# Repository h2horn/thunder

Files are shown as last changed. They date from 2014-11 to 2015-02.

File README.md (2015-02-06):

Lightning Thunder
=================

Controlling [LPD8806](https://www.adafruit.com/products/306) based LED Strips over Network.

* control up to 4 LPD8806 based LED Strips
* simple UDP Protocol

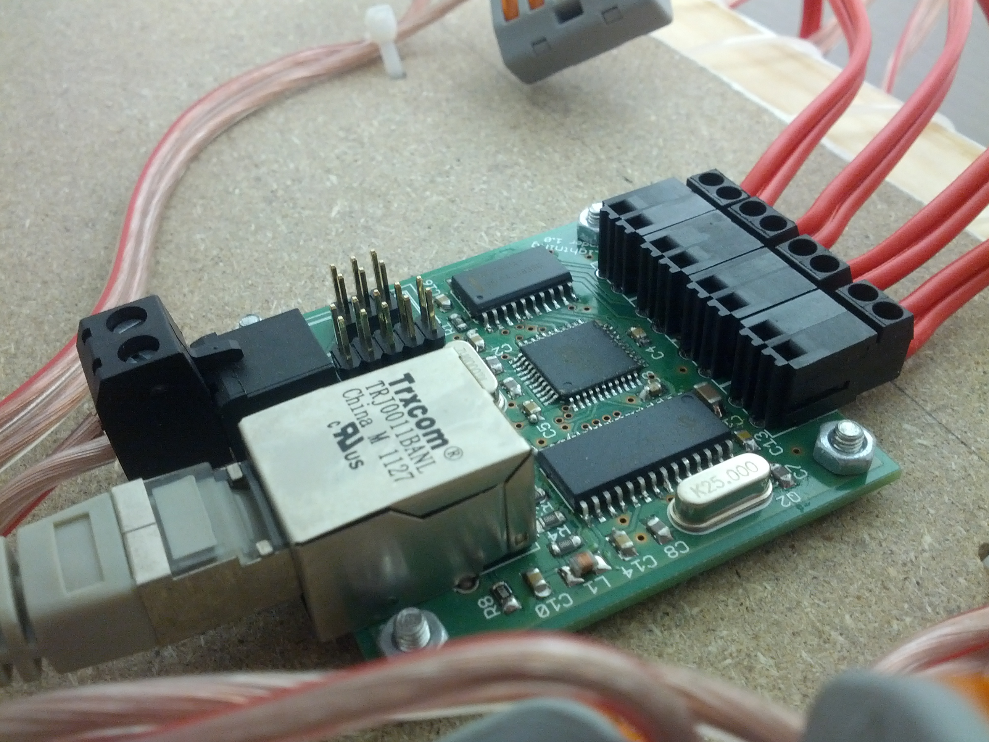
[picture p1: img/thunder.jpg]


Components
----------

Based on:

* [ATxmega16A4](http://www.atmel.com/Images/Atmel-8331-8-and-16-bit-AVR-Microcontroller-XMEGA-AU_Manual.pdf) - Low power, high performance 8/16-bit AVR microcontroller
* [ENC28J60](http://ww1.microchip.com/downloads/en/DeviceDoc/39662e.pdf) - Microchip 10Mbit Ethernet controller with SPI interface

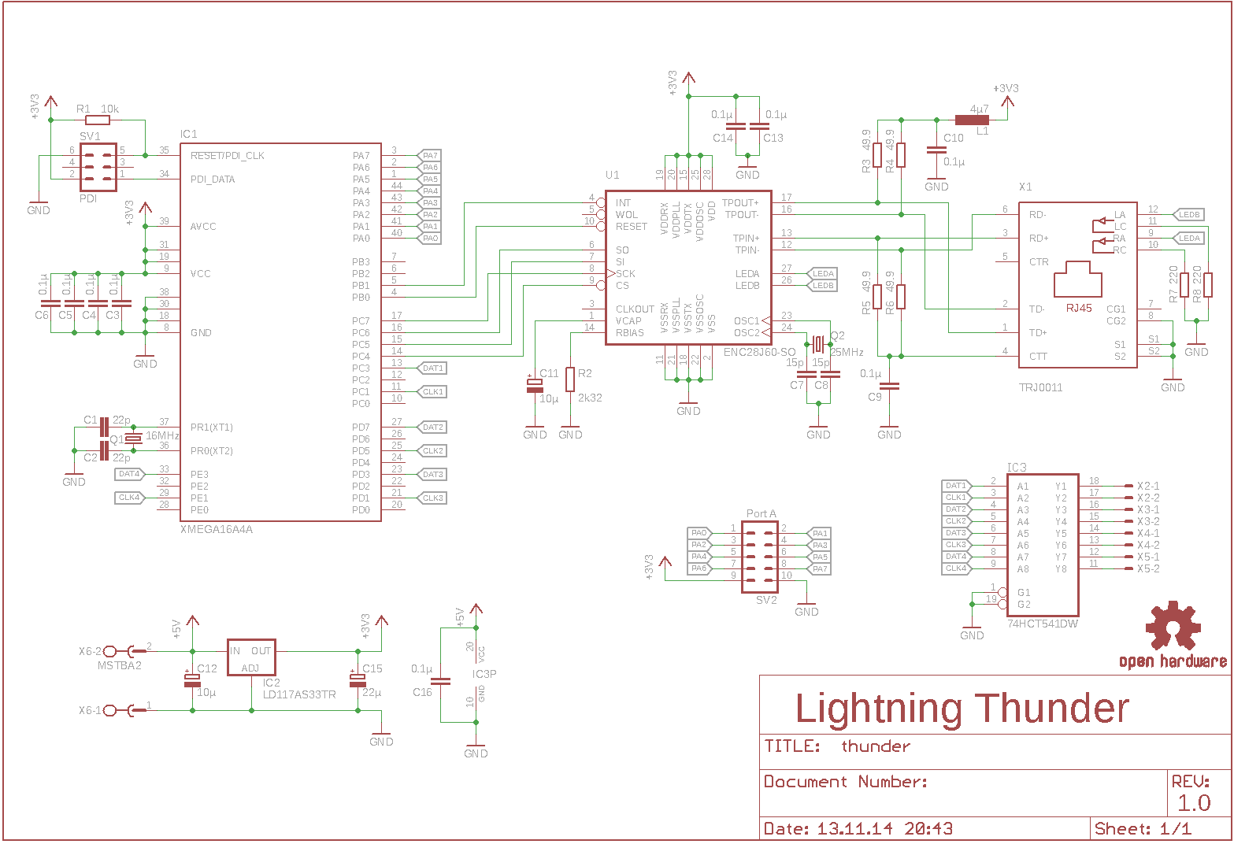
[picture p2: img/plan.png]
plan


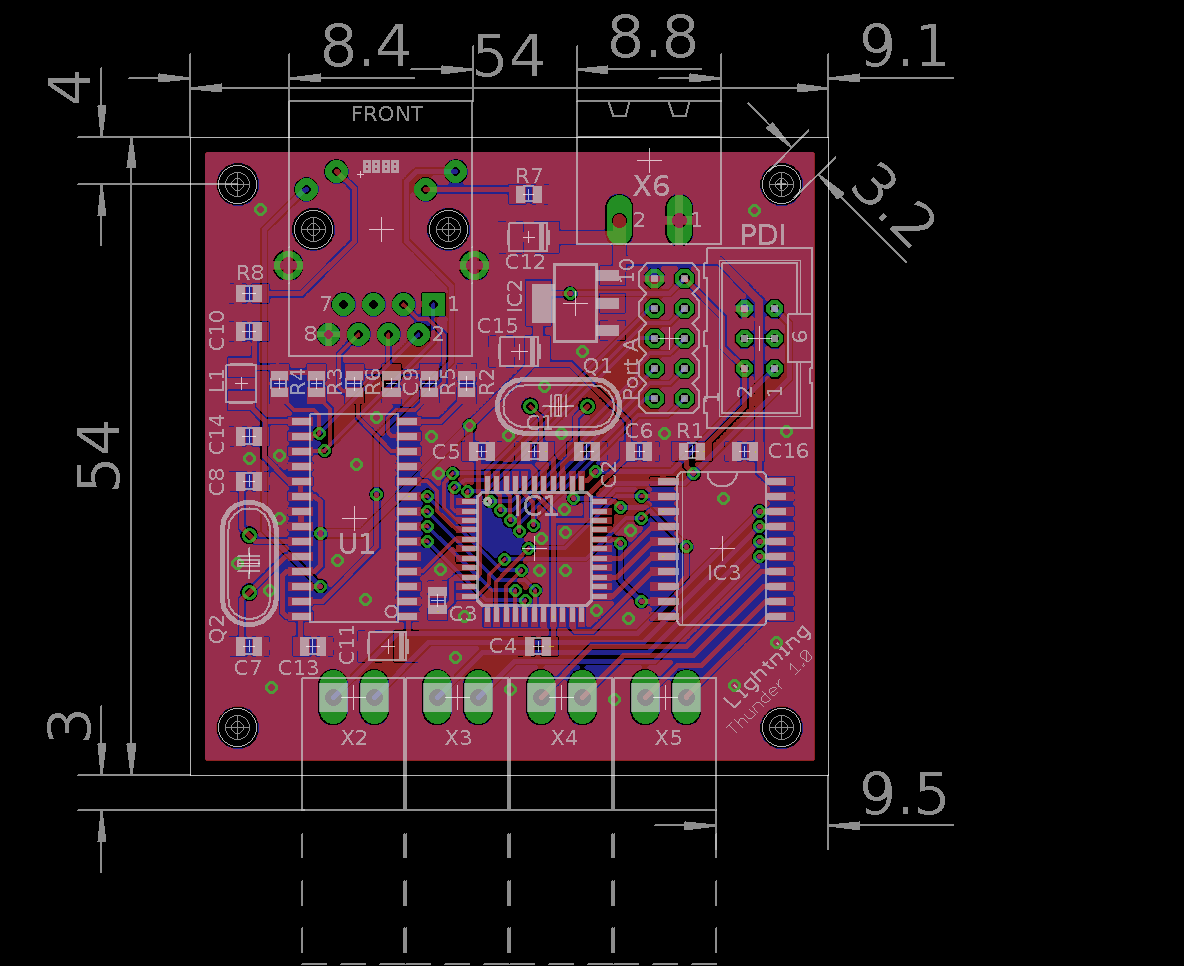
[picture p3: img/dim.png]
dim


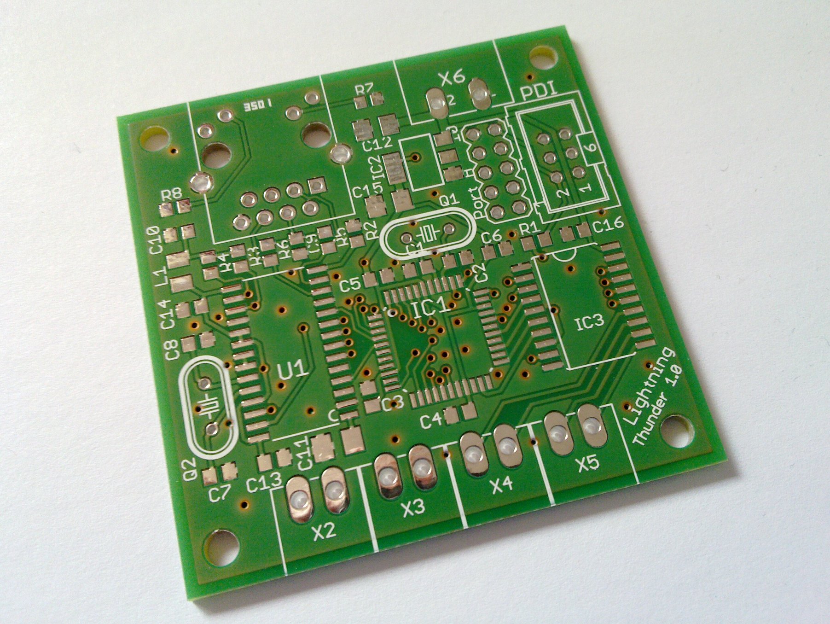
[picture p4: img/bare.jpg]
bare


Protocol
--------

`Thunder` recieves UDP data containing the raw LPD8806 data for each Strip
on seperate UDP Ports (50000-50003). It forwards the data directly over SPI, without any checking or modification.

The Host has full control and has to calculate the correct order and
color ordering (RBG -> RGB), etc...

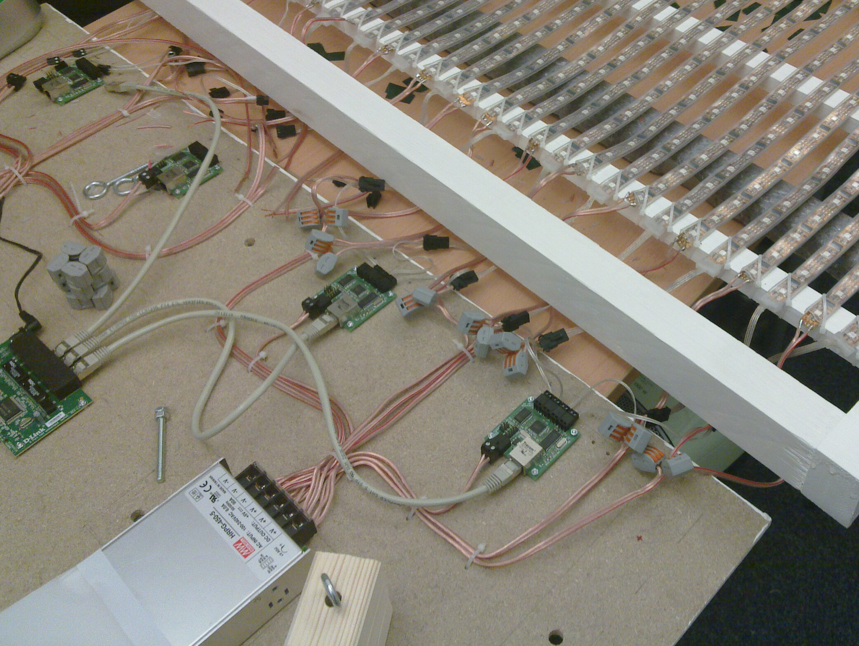
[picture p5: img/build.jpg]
build


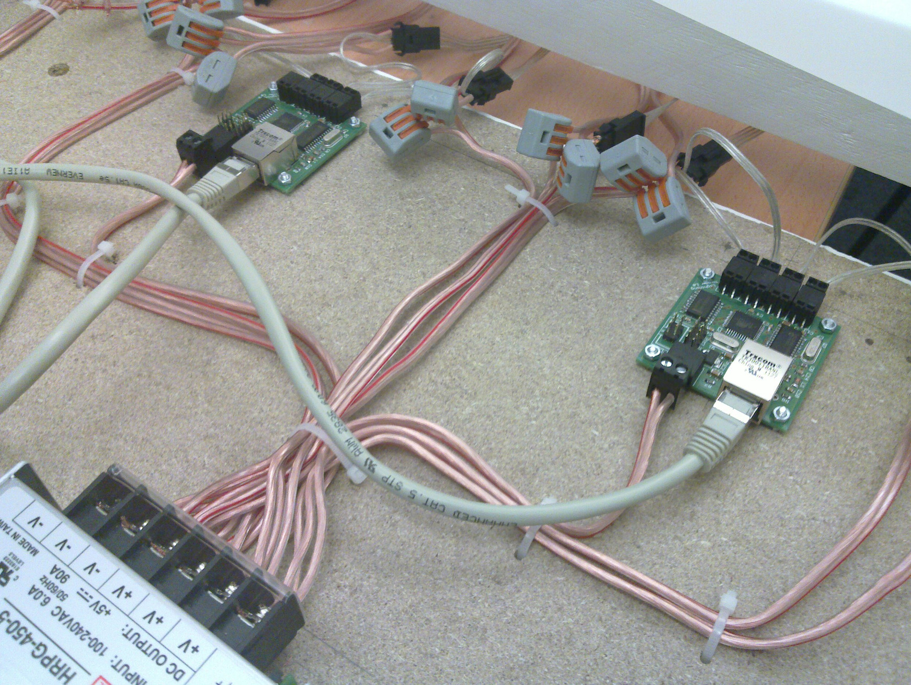
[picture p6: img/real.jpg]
real


Result
------

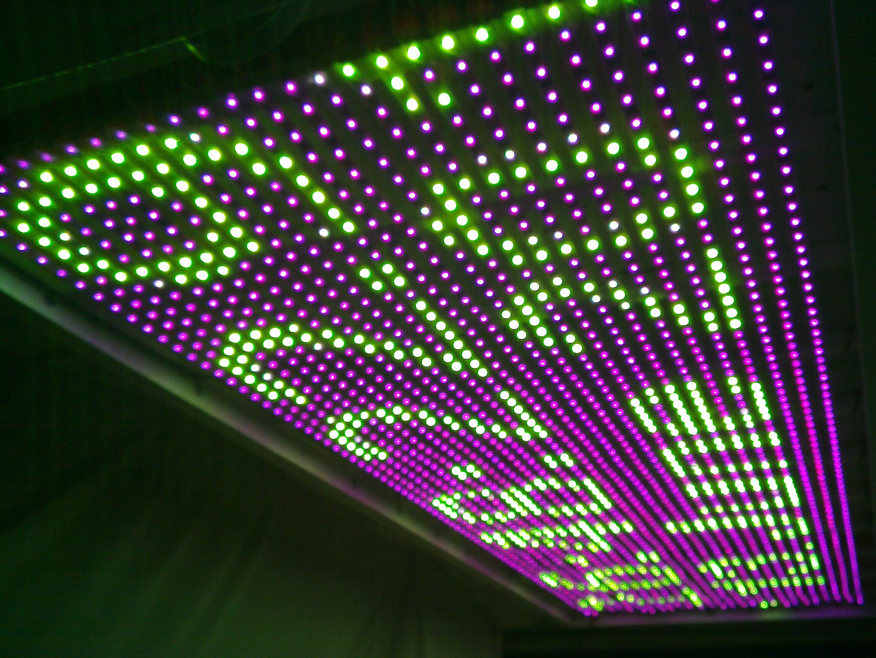
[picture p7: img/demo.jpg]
demo


LICENSE
-------

Released under the [MIT](http://opensource.org/licenses/MIT) License.
Based on the [Open Source Hardware Definition v1.0](http://www.oshwa.org/definition/).

See the respective source code files for varying Licenses.

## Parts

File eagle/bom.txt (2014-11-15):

Qty Value       Device            Package     Parts                                  Description
2   22p         C-EUC0805         C0805       C1, C2                                 CAPACITOR, European symbol
9   0.1µ        C-EUC0805         C0805       C3, C4, C5, C6, C9, C10, C13, C14, C16 CAPACITOR, European symbol
2   15p         C-EUC0805         C0805       C7, C8                                 CAPACITOR, European symbol
2   10µ         CPOL-EUB/3528-21R B/3528-21R  C11, C12                               POLARIZED CAPACITOR, European symbol
1   22µ         CPOL-EUB/3528-21R B/3528-21R  C15                                    POLARIZED CAPACITOR, European symbol
1   10k         R-EU_R0805        R0805       R1                                     RESISTOR, European symbol
2   220         R-EU_R0805        R0805       R7, R8                                 RESISTOR, European symbol
1   2k32        R-EU_R0805        R0805       R2                                     RESISTOR, European symbol
4   49.9        R-EU_R0805        R0805       R3, R4, R5, R6                         RESISTOR, European symbol
1   16MHz       CRYSTALHC49U-V    HC49U-V     Q1                                     CRYSTAL
1   25MHz       CRYSTALHC49U-V    HC49U-V     Q2                                     CRYSTAL
1   4µ7         L-EUL3225M        L3225M      L1                                     INDUCTOR, European symbol
1   XMEGA16A4A  XMEGA16A4A        TQFP44      IC1                                    MICROCONTROLLER
1   ENC28J60-SO ENC28J60-SO       SO28W       U1                                     Microchip 10Mbit Ethernet controller with SPI interface
1   LD117AS33TR LD117AS33TR       SOT223      IC2                                    Low drop fixed and adjustable positive voltage regulators 1 A
1   74HCT541DW  74HCT541DW        SO20W       IC3                                    Octal BUFFER and LINE DRIVER, 3-state
1   TRJ0011     TRJ0011           TRJ0011     X1                                     10/100Base-TX RJ45 Connector With Integrated Magnetics(Tab-Down)
4   AKL18X-02W  AKL18X-02W        AKL182-02   X2, X3, X4, X5                         Riacon AKL18X Steckverbinder
1   MSTBA2      MSTBA2            MSTBA2      X6                                     PHOENIX
1   PDI         ML6               ML6         SV1                                    HARTING
1   Port A      MA05-2            MA05-2      SV2                                    PIN HEADER

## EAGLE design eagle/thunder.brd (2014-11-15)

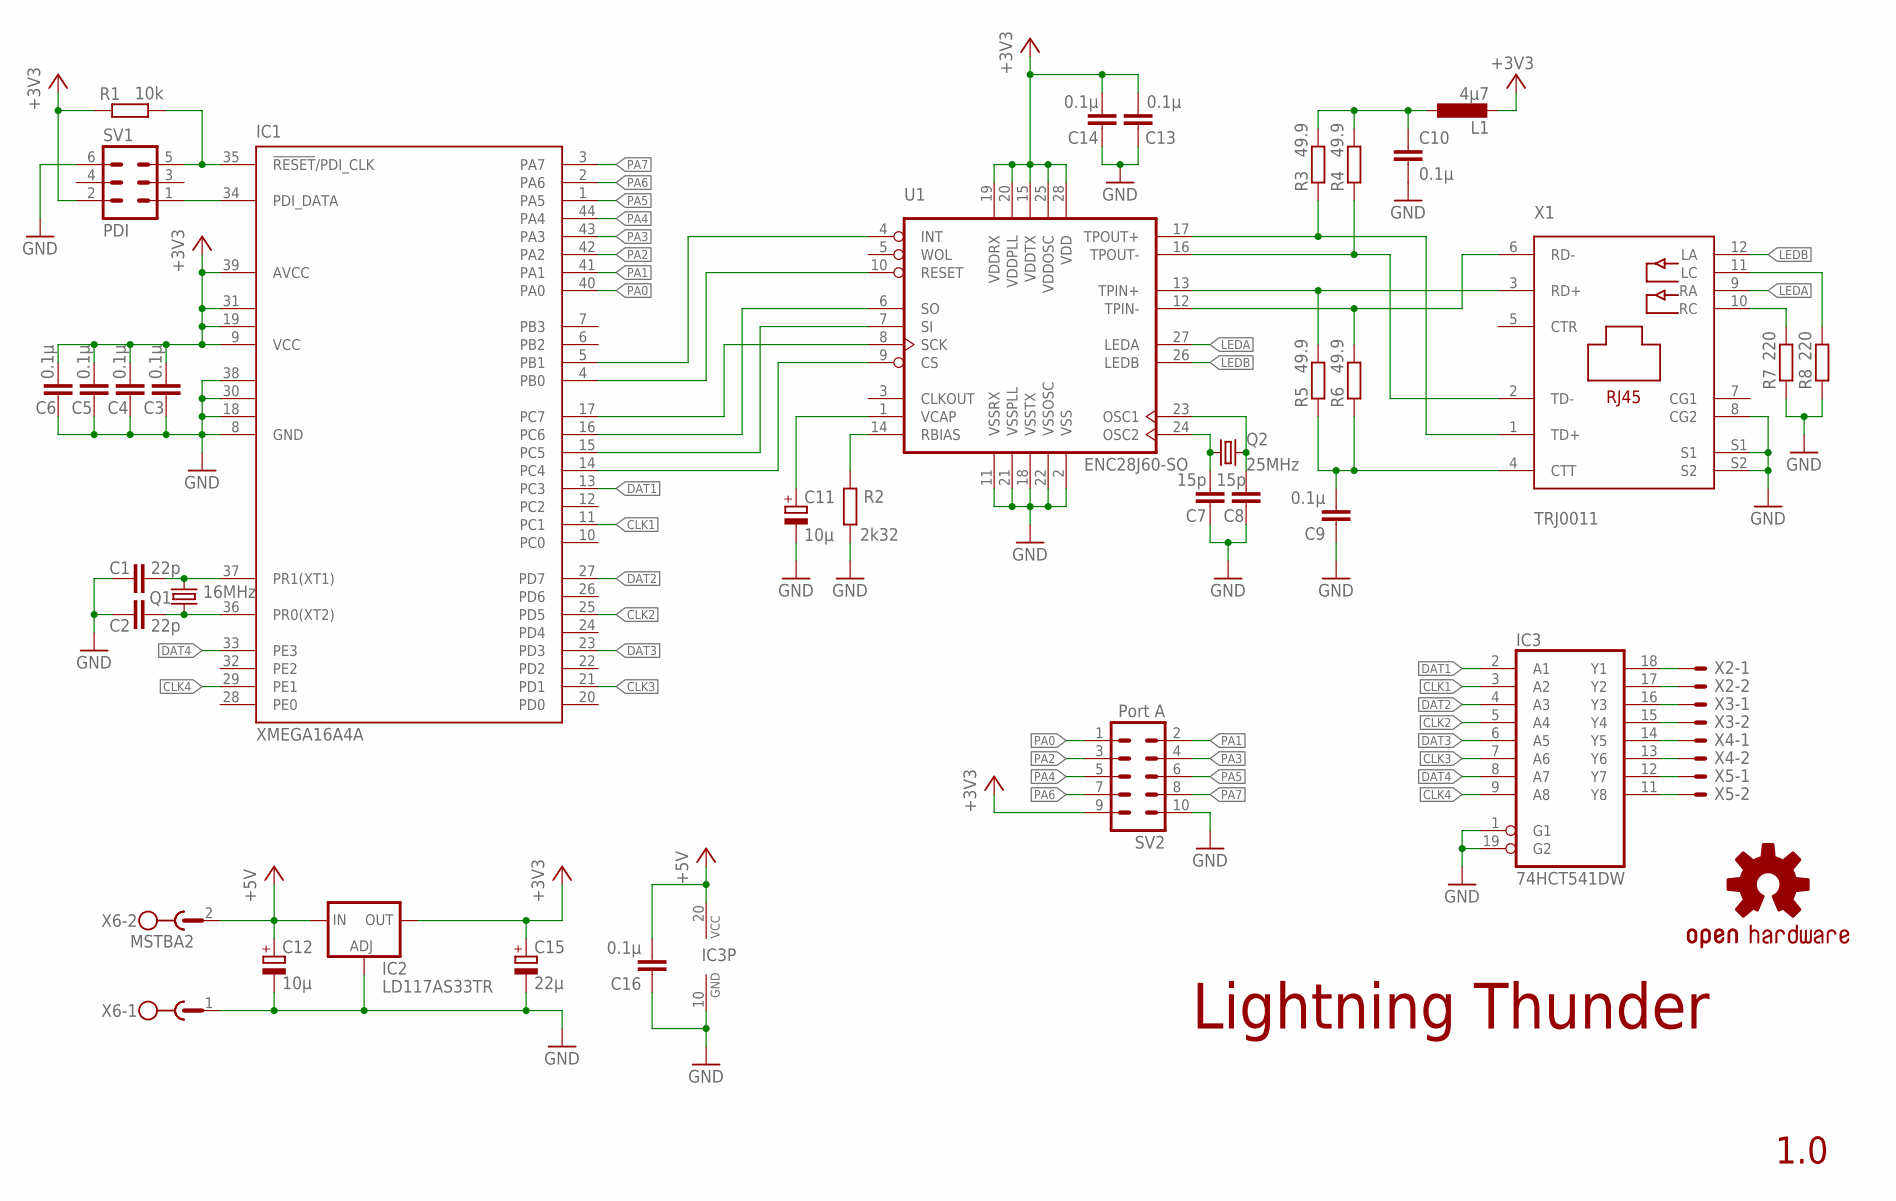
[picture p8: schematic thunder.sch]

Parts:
C1, C2: 22p; C0805
C3, C4, C5, C6, C9, C10, C13, C14, C16: 0.1µ; C0805
C7, C8: 15p; C0805
C11, C12: 10µ; B/3528-21R
C15: 22µ; B/3528-21R
IC1: XMEGA16A4A; TQFP44
IC2: LD117AS33TR; SOT223
IC3: 74HCT541DW; SO20W
L1: 4µ7; L3225M
LOGO1: OSHW-LOGOS; OSHW-LOGO-S
Q1: 16MHz; HC49U-V
Q2: 25MHz; HC49U-V
R1: 10k; R0805
R2: 2k32; R0805
R3, R4, R5, R6: 49.9; R0805
R7, R8: 220; R0805
SV1: PDI; ML6
SV2: Port A; MA05-2
U1: ENC28J60-SO; SO28W
X1: TRJ0011
X2, X3, X4, X5: AKL18X-02W; AKL182-02
X6: MSTBA2

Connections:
+3V3: C3.2, C4.2, C5.2, C6.2, C13.2, C14.2, C15.+, IC1.9 (VCC), IC1.19 (VCC1), IC1.31 (VCC2), IC1.39 (AVCC), IC2.4 (OUT), L1.2, R1.2, SV1.2, SV2.9, U1.15 (VDDTX), U1.19 (VDDRX), U1.20 (VDDPLL), U1.25 (VDDOSC), U1.28 (VDD)
+5V: C12.+, C16.2, IC2.3 (IN), IC3.20 (VCC), X6.2
CLK1: IC1.11 (PC1), IC3.3 (A2)
CLK2: IC1.25 (PD5), IC3.5 (A4)
CLK3: IC1.21 (PD1), IC3.7 (A6)
CLK4: IC1.29 (PE1), IC3.9 (A8)
DAT1: IC1.13 (PC3), IC3.2 (A1)
DAT2: IC1.27 (PD7), IC3.4 (A3)
DAT3: IC1.23 (PD3), IC3.6 (A5)
DAT4: IC1.33 (PE3), IC3.8 (A7)
GND: C1.1, C2.1, C3.1, C4.1, C5.1, C6.1, C7.1, C8.1, C9.1, C10.2, C11.-, C12.-, C13.1, C14.1, C15.-, C16.1, IC1.8 (GND), IC1.18 (GND1), IC1.30 (GND2), IC1.38 (GND3), IC2.1 (ADJ), IC3.1 (G1), IC3.10 (GND), IC3.19 (G2), R2.1, R7.1, R8.1, SV1.6, SV2.10, U1.2 (VSS), U1.11 (VSSRX), U1.18 (VSSTX), U1.21 (VSSPLL), U1.22 (VSSOSC), X1.8 (CG2), X1.S1, X1.S2, X6.1
LEDA: U1.27 (LEDA), X1.9 (RA)
LEDB: U1.26 (LEDB), X1.12 (LA)
unnamed: IC1.34 (PDI_DATA), SV1.1
unnamed: IC1.35 (!RESET!/PDI_CLK), R1.1, SV1.5
unnamed: C2.2, IC1.36 (PR0(XT2)), Q1.1
unnamed: C1.2, IC1.37 (PR1(XT1)), Q1.2
unnamed: IC1.14 (PC4), U1.9 (CS)
unnamed: IC1.17 (PC7), U1.8 (SCK)
unnamed: IC1.16 (PC6), U1.6 (SO)
unnamed: IC1.15 (PC5), U1.7 (SI)
unnamed: IC1.4 (PB0), U1.10 (RESET)
unnamed: IC1.5 (PB1), U1.4 (INT)
unnamed: R3.1, U1.17 (TPOUT+), X1.1 (TD+)
unnamed: R4.1, U1.16 (TPOUT-), X1.2 (TD-)
unnamed: R5.2, U1.13 (TPIN+), X1.3 (RD+)
unnamed: R6.2, U1.12 (TPIN-), X1.6 (RD-)
unnamed: R2.2, U1.14 (RBIAS)
unnamed: C10.1, L1.1, R3.2, R4.2
unnamed: C9.2, R5.1, R6.1, X1.4 (CTT)
unnamed: C11.+, U1.1 (VCAP)
unnamed: IC3.18 (Y1), X2.P$1
unnamed: C7.2, Q2.1, U1.24 (OSC2)
unnamed: C8.2, Q2.2, U1.23 (OSC1)
unnamed: IC3.17 (Y2), X2.P$2
unnamed: IC3.16 (Y3), X3.P$1
unnamed: IC3.15 (Y4), X3.P$2
unnamed: R7.2, X1.10 (RC)
unnamed: R8.2, X1.11 (LC)
unnamed: IC3.14 (Y5), X4.P$1
unnamed: IC3.13 (Y6), X4.P$2
unnamed: IC3.12 (Y7), X5.P$1
unnamed: IC3.11 (Y8), X5.P$2
PA0: IC1.40 (PA0), SV2.1
PA1: IC1.41 (PA1), SV2.2
PA2: IC1.42 (PA2), SV2.3
PA3: IC1.43 (PA3), SV2.4
PA4: IC1.44 (PA4), SV2.5
PA5: IC1.1 (PA5), SV2.6
PA6: IC1.2 (PA6), SV2.7
PA7: IC1.3 (PA7), SV2.8

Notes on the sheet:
Lightning Thunder
1.0

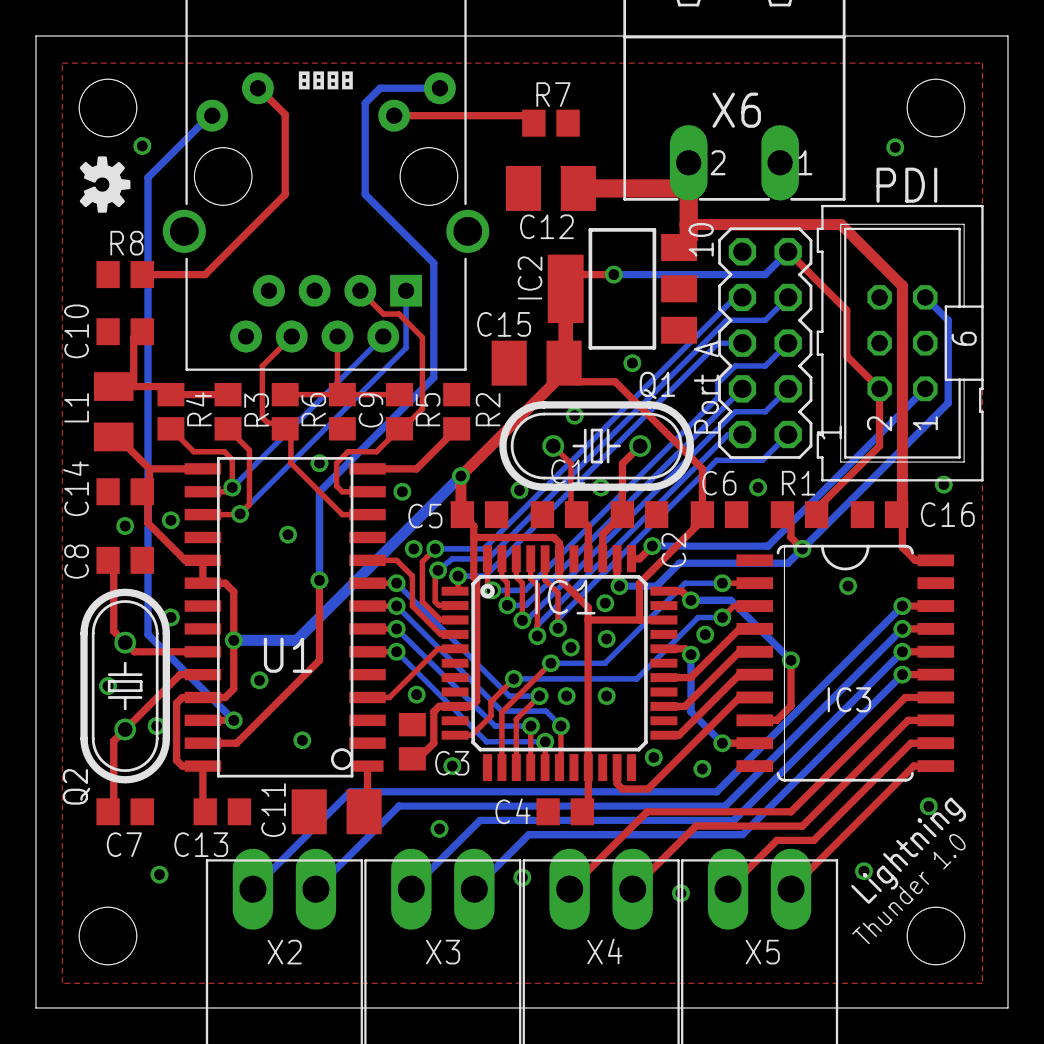
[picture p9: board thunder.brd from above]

Board: 2 copper layers, 54.0 x 54.0 mm, 41 parts (0 on the bottom side), 51 nets.

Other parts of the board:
U$1: LP_NUMBER_SILK_TOP

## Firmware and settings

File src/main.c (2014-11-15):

#include <avr/io.h>
#define F_CPU 32000000UL
#include <util/delay.h>
#include <avr/interrupt.h>
#include <stdio.h>
#include "lpd8806.h"
#include "ethernet.h"
#include "dma.h"
#include <stddef.h>
#include <avr/pgmspace.h> 

// #define _DEBUG_
void uart_init(void);
void adc_init(void);

#define BAUD_VAL 115200						// baudrate fuer usart-uebertragung
#define BSEL_VAL ((F_CPU/(16*BAUD_VAL))-1)	// berechnung fuer baudraten-registerwert

#ifdef _DEBUG_
	static int uart_write_char(char c, FILE *stream);
	static FILE mystdout = FDEV_SETUP_STREAM (uart_write_char, NULL, _FDEV_SETUP_WRITE);
#endif

// Prototypes
void clock_init(void);

// Vars
uint8_t buffer[480];
uint8_t state = 0;

int main(void) {
	PORTA.DIR = 0xFF;
	clock_init();

	// Interrupt init
	PMIC.CTRL |= PMIC_HILVLEN_bm | PMIC_MEDLVLEN_bm | PMIC_LOLVLEN_bm;
	sei();

	dma_init();
	writeLatch();

#ifdef _DEBUG_
	uart_init();    
	stdout = &mystdout;
#endif

	ethernet_init();

#ifdef _DEBUG_
	printf("Hello, world!\n");
#endif

	// adc_init();

	PORTA.DIR = 0xFF;
	PORTA.OUT = 0xFF;
	// PORTA.OUTTGL = 0xFF;
	// writeLatch();

	// USARTD0.DATA = 0x00;
	// while(!(USARTD0.STATUS & USART_DREIF_bm));

	// showLed();
	// writeLatch();
	// showLed();
	// writeLatch();
	// _delay_ms(2000);
	// showLed();
	// writeLatch();

	while (1) {
		check_ethernet();
		// PORTA.OUTTGL = 0xFF;
		// printf("T %u\n", ADCA.CH0RES);
		// printf("Temp %u C\n", ADCA.CH0RES * 85 / 2642);
		// _delay_ms(5000);

	}
}

void clock_init() {
	// 32Mhz
	OSC.CTRL |= OSC_RC32MEN_bm;
	// Warten bis Oszillator
	while(!(OSC.STATUS & OSC_RC32MRDY_bm));

	//Configuration Change Protection Register
	CCP = 0xD8;
	//Select 32Mhz OSC
	CLK.CTRL = (CLK.CTRL & ~CLK_SCLKSEL_gm) | CLK_SCLKSEL_RC32M_gc;
}

void uart_init() {
	PORTC.OUT = (0<<PIN2) | (1<<PIN3);	// laut datenblatt TX-pin auf high setzen
	PORTC.DIR = (0<<PIN2) | (1<<PIN3);	// RX-pin als eingang, TX-pin als ausgang
	
	USARTC0.BAUDCTRLB = 0;			// wert passt in 8bit-register, also B-register und skalierungsfaktor 0
	USARTC0.BAUDCTRLA = BSEL_VAL;	// baudratenwert in register schreiben
	
	USARTC0.CTRLA = 0;		// keine interrupt oder sonstiges
	USARTC0.CTRLC = USART_CMODE_ASYNCHRONOUS_gc | USART_PMODE_DISABLED_gc | USART_CHSIZE_8BIT_gc;	// modus: asynchron | parity: keines | stop-bits: 1 | character-size: 8bit
	USARTC0.CTRLB = USART_RXEN_bm | USART_TXEN_bm;	// empfaenger und transmitter aktivieren
	
	return;
}

#ifdef _DEBUG_
static int uart_write_char(char c, FILE *stream) {
	if (c == '\n')
        uart_write_char('\r', stream);

	while(!(USARTC0.STATUS & USART_DREIF_bm)) {}	// warten, bis das datenregister leer ist
	USARTC0.DATA = c;		// daten senden	

	return 0;
}
#endif

void adc_init() {
	ADCA.CTRLB = ADC_CONMODE_bm | ADC_RESOLUTION_12BIT_gc | ADC_FREERUN_bm;
	ADCA.REFCTRL = ADC_REFSEL_INT1V_gc | ADC_TEMPREF_bm;
	ADCA.EVCTRL = ADC_SWEEP_0_gc;
	ADCA.PRESCALER = ADC_PRESCALER_DIV512_gc;
	ADCA.CAL = 0x01FF; /* ADCACAL0 : ADCACAL1 */
	ADCA.CH0.CTRL = ADC_CH_GAIN_1X_gc | ADC_CH_INPUTMODE_INTERNAL_gc;
	ADCA.CH0.MUXCTRL = ADC_CH_MUXINT_TEMP_gc;
	ADCA.CTRLA = ADC_ENABLE_bm;
	ADCA.CH0.CTRL = ADC_CH_START_bm;

#ifdef _DEBUG_
	int tcal;
	NVM_CMD = NVM_CMD_READ_CALIB_ROW_gc;
	tcal = pgm_read_byte(offsetof(NVM_PROD_SIGNATURES_t, TEMPSENSE1)) << 8;
	tcal |= pgm_read_byte(offsetof(NVM_PROD_SIGNATURES_t, TEMPSENSE0));
	NVM_CMD = NVM_CMD_NO_OPERATION_gc;
	printf("Temp Cal Val %u \n", tcal);
#endif
}

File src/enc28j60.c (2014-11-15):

/*! \file enc28j60.c \brief Microchip ENC28J60 Ethernet Interface Driver. */
//*****************************************************************************
//
// File Name	: 'enc28j60.c'
// Title		: Microchip ENC28J60 Ethernet Interface Driver
// Author		: Pascal Stang (c)2005
// Created		: 9/22/2005
// Revised		: 9/22/2005
// Version		: 0.1
// Target MCU	: Atmel AVR series
// Editor Tabs	: 4
//
// Description	: This driver provides initialization and transmit/receive
//	functions for the Microchip ENC28J60 10Mb Ethernet Controller and PHY.
// This chip is novel in that it is a full MAC+PHY interface all in a 28-pin
// chip, using an SPI interface to the host processor.
//
//*****************************************************************************
#include <avr/io.h>
#include <avr/interrupt.h>
#include "config.h"
#include <util/delay.h>
#include <stdio.h>
#include "enc28j60.h"

#include "spi.h"


unsigned char Enc28j60Bank;
unsigned int NextPacketPtr;

//*********************************************************************************************************
//
// Setzt die MAC-Adressse im Enc28j60
//
//*********************************************************************************************************
void nicSetMacAddress( char * MAC)
{
	// write MAC address
	// NOTE: MAC address in ENC28J60 is byte-backward
  	enc28j60Write(MAADR5, MAC[ 0 ] );
	enc28j60Write(MAADR4, MAC[ 1 ] );
	enc28j60Write(MAADR3, MAC[ 2 ] );
	enc28j60Write(MAADR2, MAC[ 3 ] );
	enc28j60Write(MAADR1, MAC[ 4 ] );
	enc28j60Write(MAADR0, MAC[ 5 ] );
}

//*********************************************************************************************************
//
// Sende Rad Command
//
//*********************************************************************************************************
char enc28j60ReadOp( char op, char address)
{
	char temp_sreg;
	temp_sreg = SREG;
	cli();

	unsigned char data;
	// CS aktive setzen
	ENC28J60_CONTROL_PORT.OUTCLR = ( 1<<ENC28J60_CONTROL_CS );
	// lesecomando schreiben
	data = SPI_ReadWrite( SPIBUS, op | (address & ADDR_MASK) );
	// dummy senden um ergebnis zu erhalten
	data = SPI_ReadWrite( SPIBUS, 0x00 );
	// dummy read machen
	if ( address & 0x80 )
		data = SPI_ReadWrite( SPIBUS, 0x00 );
	// CS wieder freigeben
	_delay_us( 1 );
	
	ENC28J60_CONTROL_PORT.OUTSET = (1<<ENC28J60_CONTROL_CS);

	SREG = temp_sreg;

	return data;
}

//*********************************************************************************************************
//
// Sende Write Command
//
//*********************************************************************************************************
void enc28j60WriteOp( char op, char address, char data)
{
	char temp_sreg;
	temp_sreg = SREG;
	cli();
	
	// CS aktive setzen
	ENC28J60_CONTROL_PORT.OUTCLR = ( 1<<ENC28J60_CONTROL_CS );
	// schreibcomando senden
	SPI_ReadWrite( SPIBUS, op | (address & ADDR_MASK) );
	// daten senden
	SPI_ReadWrite( SPIBUS, data );
	// CS wieder freigeben
	_delay_us( 1 );

	ENC28J60_CONTROL_PORT.OUTSET = (1<<ENC28J60_CONTROL_CS);

	SREG = temp_sreg;
}

//*********************************************************************************************************
//
// Buffer einlesen
//
//*********************************************************************************************************
void enc28j60ReadBuffer( int len, char * data)
{
	char temp_sreg;
	temp_sreg = SREG;
	cli();

	// assert CS
	ENC28J60_CONTROL_PORT.OUTCLR = ( 1<<ENC28J60_CONTROL_CS );
	// issue read command
	SPI_ReadWrite( SPIBUS, ENC28J60_READ_BUF_MEM );

	SPI_ReadBlock( SPIBUS, data, len);
	// while(len--)
	// {
	// 	// read data
	// 	*data++ = SPI_ReadWrite( SPIBUS, 0x00 );
	// } 

	// release CS
	_delay_us( 1 );

	ENC28J60_CONTROL_PORT.OUTSET = (1<<ENC28J60_CONTROL_CS);
	
	SREG = temp_sreg;
}

//*********************************************************************************************************
//
// Buffer schreiben
//
//*********************************************************************************************************
void enc28j60WriteBuffer( int len, char * data)
{
	char temp_sreg;
	temp_sreg = SREG;
	cli();

	// assert CS
	ENC28J60_CONTROL_PORT.OUTCLR = ( 1<<ENC28J60_CONTROL_CS );
	
	// issue write command
	SPI_ReadWrite( SPIBUS, ENC28J60_WRITE_BUF_MEM );

//	SPI1_FastMem2Write( data, len );
	while(len--)
	{
		// write data
		SPI_ReadWrite( SPIBUS, *data++ );
	}
	// release CS
	_delay_us( 1 );

	ENC28J60_CONTROL_PORT.OUTSET = (1<<ENC28J60_CONTROL_CS);
	SREG = temp_sreg;
}

//*********************************************************************************************************
//
// 
//
//*********************************************************************************************************
void enc28j60SetBank(char address)
{
	// set the bank (if needed)
	if((address & BANK_MASK) != Enc28j60Bank)
	{
		// set the bank
		enc28j60WriteOp(ENC28J60_BIT_FIELD_CLR, ECON1, (ECON1_BSEL1|ECON1_BSEL0));
		enc28j60WriteOp(ENC28J60_BIT_FIELD_SET, ECON1, (address & BANK_MASK)>>5);
		Enc28j60Bank = (address & BANK_MASK);
	}
}

//*********************************************************************************************************
//
// 
//
//*********************************************************************************************************
char enc28j60Read( char address)
{
	// set the bank
	enc28j60SetBank(address);
	// do the read
	return enc28j60ReadOp(ENC28J60_READ_CTRL_REG, address);
}

//*********************************************************************************************************
//
// 
//
//*********************************************************************************************************
void enc28j60Write( char address, char data)
{
	// set the bank
	enc28j60SetBank(address);
	// do the write
	enc28j60WriteOp(ENC28J60_WRITE_CTRL_REG, address, data);
}

//*********************************************************************************************************
//
// 
//
//*********************************************************************************************************
int enc28j60PhyRead( char address)
{
     int data;
 
     // Set the right address and start the register read operation
     enc28j60Write(MIREGADR, address);
     enc28j60Write(MICMD, MICMD_MIIRD);
 
    // wait until the PHY read completes
     while(enc28j60Read(MISTAT) & MISTAT_BUSY);
 
     // quit reading
     enc28j60Write(MICMD, 0x00);
     
     // get data value
     data  = enc28j60Read(MIRDL);
     data |= enc28j60Read(MIRDH)<<8;
     // return the data
     return data;
}
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

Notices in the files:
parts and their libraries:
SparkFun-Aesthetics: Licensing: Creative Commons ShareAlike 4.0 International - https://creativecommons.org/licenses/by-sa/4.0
